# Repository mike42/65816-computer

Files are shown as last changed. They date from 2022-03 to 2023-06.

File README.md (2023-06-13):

# 65816 computer 

This is a prototype 65C816-based computer. It features a 1.8432 MHz processor, 1 megabyte of static RAM, a 65C22 I/O port, and an NXP SC16C752 dual UART.

The ROM contains a simple test program.

## Blog series

This is a learning project, and I am blogging about it as I progress.

- [A first look at the 65C816 processor](https://mike42.me/blog/2022-01-a-first-look-at-the-65c816-processor)
- [65C816 computer - initial prototype](https://mike42.me/blog/2022-02-65c816-computer-initial-prototype)
- [Interfacing an NXP UART to an 8-bit computer](https://mike42.me/blog/2022-02-interfacing-an-nxp-uart-to-an-8-bit-computer)
- [Let’s implement preemptive multitasking](https://mike42.me/blog/2022-03-lets-implement-preemptive-multitasking)
- [Building an emulator for my 65C816 computer](https://mike42.me/blog/2022-04-building-an-emulator-for-my-65c816-computer)
- [65C816 computer - second prototype](https://mike42.me/blog/2022-05-65c816-computer-second-prototype)
- [Building a 65C816 test board](https://mike42.me/blog/2022-06-building-a-65c816-test-board)
- [Let’s implement power-on self test (POST)](https://mike42.me/blog/2022-06-lets-implement-power-on-self-test-post)
- [Let’s make a bootloader – Part 1](https://mike42.me/blog/2022-09-lets-make-a-bootloader-part-1)
- [Let’s make a bootloader – Part 2](https://mike42.me/blog/2022-09-lets-make-a-bootloader-part-2)
- [Converting my 65C816 computer project to 3.3 V](https://mike42.me/blog/2023-01-converting-my-65c816-computer-project-to-3-3-v)

## Licenses & acknowledgement

With the exception of the files noted below, this work is © 2022-2023 Michael Billington, and is licensed under a [Creative Commons Attribution 4.0 International License](http://creativecommons.org/licenses/by/4.0/).

### 65816 emulator

The files in the `emulator/` directory are derived from Francesco Rigoni's work, primarily [lib65816](https://github.com/FrancescoRigoni/Lib65816). The emulator application is licensed under the GNU General Public License, version 3. Please see the README and LICENSE file in that directory for details.

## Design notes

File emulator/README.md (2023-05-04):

# 65816 emulator

This is an emulator for the custom 65C816 computer in this repository.

## Before you begin

You will need to assemble the computer's firmware to run the emulator. This is expected to be located at `../rom/rom.bin`.

To build the emulator itself, you will need:

- cmake - tested on 3.22.1
- GCC - tested on 11.2.0.
- Google test and boost libraries, installed on Debian via command below.

```
sudo apt install libgtest-dev libboost1.74-dev libboost-program-options1.74-dev libboost-filesystem1.74-dev
```

The emulator is only tested on Linux, and only implements hardware features which are used by the computer.

## Quick start

Compile and test a release build:

```
cmake -B build/release
make -j8 -C build/release all test
```

Run the emulator:

```
./build/release/emulator --rom ../rom/rom.bin
```

This will create a unix socket called 'serial1' in the current directory. In a separate terminal window, connect to this socket with minicom to interact with the emulated system.

```
minicom -D unix#serial
```

## Test mode

The emulator also functions as a unit test runner for the 65816 assembly projects in this repository. It uses debug information (a list of labels in VICE format) to locate and execute a `test_setup` routine, followed by every routine beginning with the name `test_`. If a routine leaves 0 in the accumulator after returning, it is recorded as a test pass. Any other value is recorded as a test failure.

An example project is located in the `test/resources/testing_example/` directory to show how this feature works. Execute the tests with the following command:

```
./build/release/emulator --test test/resources/testing_example/test.bin
```

## Fuzz tests

Fuzz tests are not built by default, since they depend on different build flags, as well as the use of clang.

Build them with the following commands:

```
CC=clang CXX=clang++ cmake -DFUZZ=1 -B build/fuzz
make -j8 -C build/fuzz
```

Next, run your fuzzer of choice from the `build/fuzz` directory.

## License & Attribution

This emulator is licensed under the GNU General Public License, version 3. See `LICENSE` for details.

It is derived from Francesco Rigoni's [lib65816](https://github.com/FrancescoRigoni/Lib65816), [Lib65816_Sample](https://github.com/FrancescoRigoni/Lib65816_Sample) and [Simple-Logger](https://github.com/FrancescoRigoni/Simple-Logger), with modifications by Michael Billington.

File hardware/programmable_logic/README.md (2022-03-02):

# Programmable logic for 65816 computer

This project PLD's to implement some functionality.

## PLD definitions

- `address_decode` - Provides chip select, read and write signals based on a memory address.

## Required tools

You will need quite a few tools to work with these files. Take a look at the `Makefile` in each directory to see how they are used.

### galette

Galette compiles the logic functions to a binary file which can be written to the PLD. See [simon-frankau/galette](https://github.com/simon-frankau/galette).

### pin_to_csv

This converts the output of galette to an input for KiPart. It was written for this project, and is included in the repo.

### KiPart

KiPart generates KiCAD symbols for the programmed PLD's. See [devbisme/KiPart](https://github.com/devbisme/KiPart)

```
pip3 install kipart
```

### minipro

This is a command-line utility which I use to program these chips. See [DavidGriffith/minipro/](https://gitlab.com/DavidGriffith/minipro/)

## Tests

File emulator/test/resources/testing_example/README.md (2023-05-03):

# Example test project

This is an assembled test project: the emulator is able to run tests in the linker binary output (test.bin), discovered by parsing the label file (test.lbl).

Source and build script are provided for reference.

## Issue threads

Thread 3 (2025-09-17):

Alternative reset button symbol.

Anathae, 2025-09-17:
As noted in your Jan 2023 blog posting, the pinout of the tactile switch used for the reset switch did not match the mapping between the schematic pins and the PCB pins.  The pinout you used, SW_TH_Tactile_Omron_BF-10xx, described in the datasheet at https://omronfs.omron.com/en_US/ecb/products/pdf/en-b3f.pdf, is better matched to the schematic symbol for SW_MEC_5E.  Pins 1 and 2 are one side of the button, and 3 and 4 are the other side of the button.  With this symbol and pinout, pin 1 on the pcb would be mapped to pins 3 and 4 on the schematic symbol, and pin 2 on the pcb would be mapped to pins 1 and 2 on the schematic symbol.

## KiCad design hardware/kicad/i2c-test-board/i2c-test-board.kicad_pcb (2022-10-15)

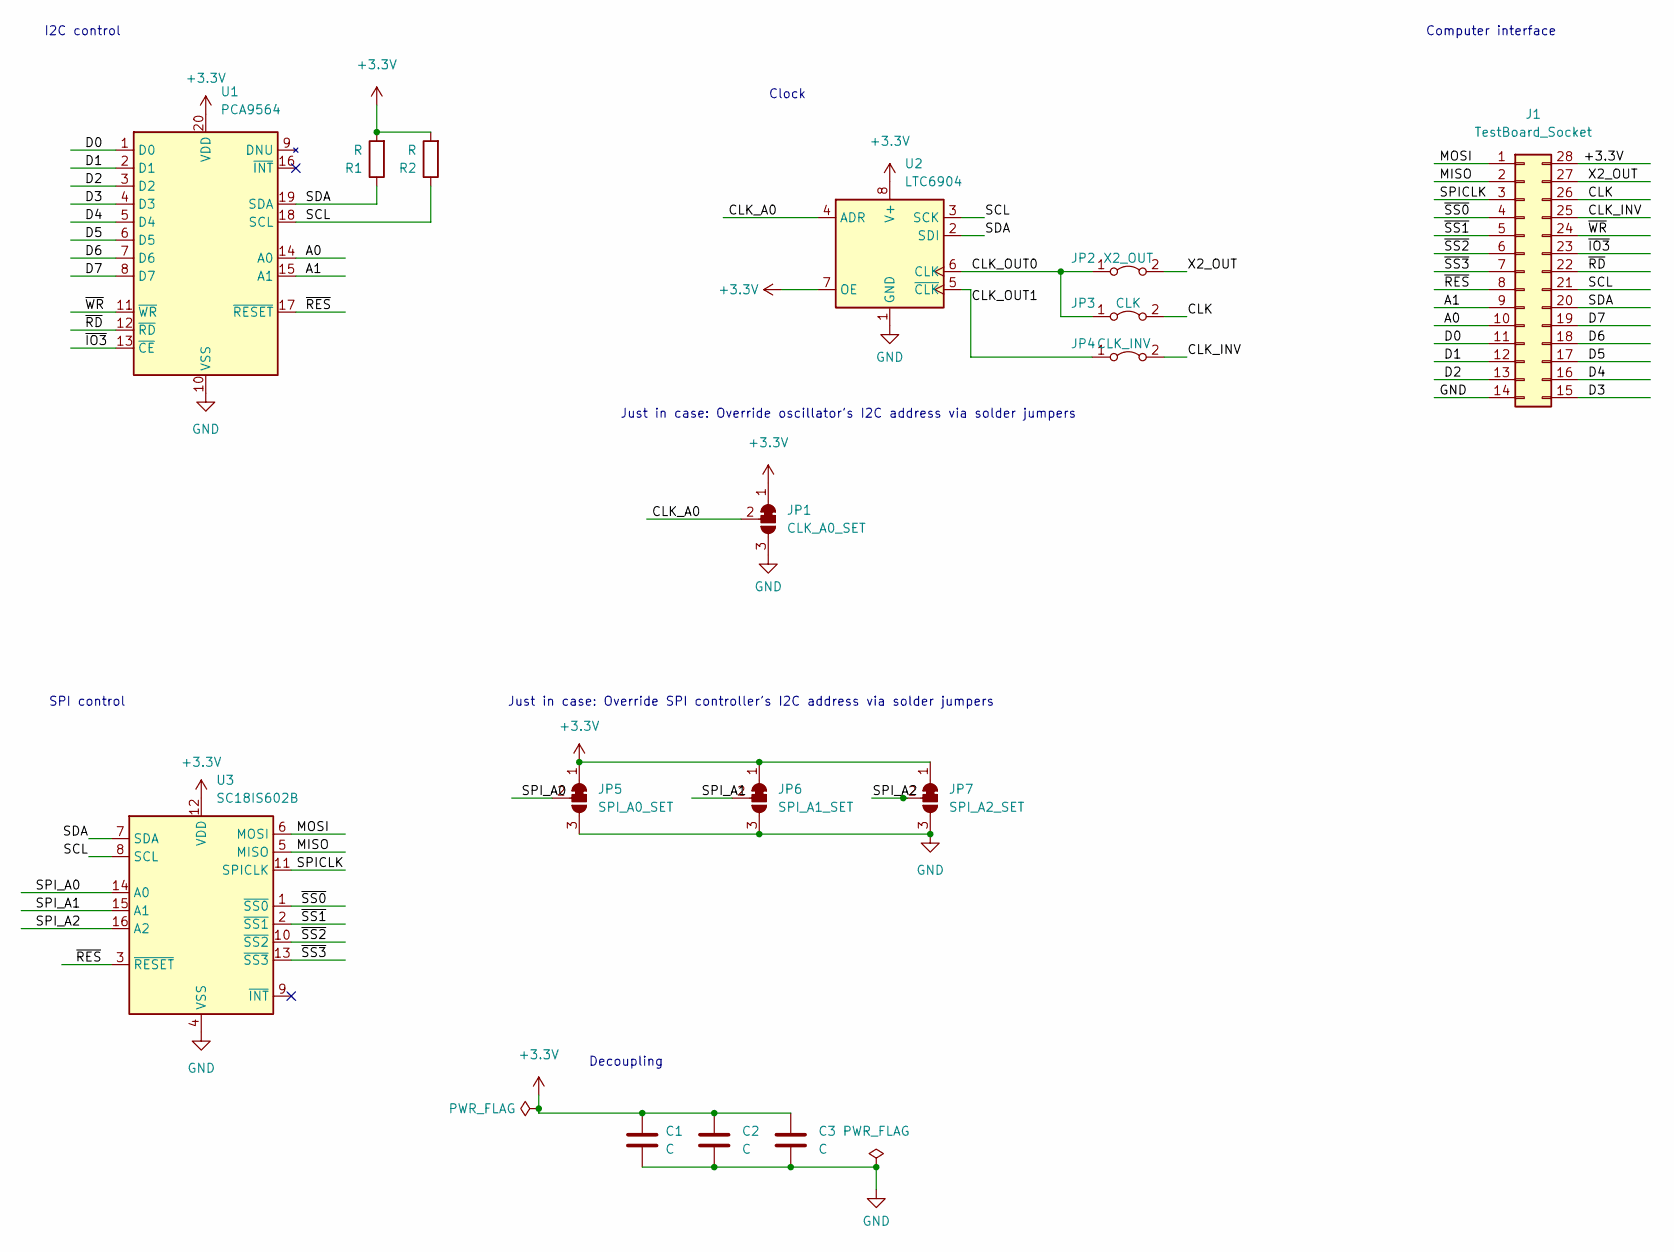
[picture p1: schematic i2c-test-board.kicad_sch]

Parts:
C1, C2, C3: C; C_0603_1608Metric_Pad1.08x0.95mm_HandSolder
J1: TestBoard_Socket; DIP-28_W15.24mm_Socket
JP1: CLK_A0_SET; SolderJumper-3_P1.3mm_Bridged12_RoundedPad1.0x1.5mm
JP2: X2_OUT; SolderJumper-2_P1.3mm_Bridged_RoundedPad1.0x1.5mm
JP3: CLK; SolderJumper-2_P1.3mm_Bridged_RoundedPad1.0x1.5mm
JP4: CLK_INV; SolderJumper-2_P1.3mm_Bridged_RoundedPad1.0x1.5mm
JP5: SPI_A0_SET; SolderJumper-3_P1.3mm_Bridged12_RoundedPad1.0x1.5mm
JP6: SPI_A1_SET; SolderJumper-3_P1.3mm_Bridged12_RoundedPad1.0x1.5mm
JP7: SPI_A2_SET; SolderJumper-3_P1.3mm_Bridged12_RoundedPad1.0x1.5mm
R1, R2: R; R_0603_1608Metric_Pad0.98x0.95mm_HandSolder
U1: PCA9564; TSSOP-20_4.4x6.5mm_P0.65mm
U2: LTC6904; MSOP-8_3x3mm_P0.65mm
U3: SC18IS602B; TSSOP-16_4.4x5mm_P0.65mm

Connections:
+3.3V: C1.1, C2.1, C3.1, J1.28, JP1.1 (A), JP5.1 (A), JP6.1 (A), JP7.1 (A), R1.2, R2.2, U1.20 (VDD), U2.7 (OE), U2.8 (V+), U3.12 (VDD)
/A0: J1.10, U1.14 (A0)
/A1: J1.9, U1.15 (A1)
/CLK: J1.26, JP3.2 (B)
/CLK_A0: JP1.2 (C), U2.4 (ADR)
/CLK_INV: J1.25, JP4.2 (B)
/CLK_OUT0: JP2.1 (A), JP3.1 (A), U2.6 (CLK)
/CLK_OUT1: JP4.1 (A), U2.5 (~CLK)
/D0: J1.11, U1.1 (D0)
/D1: J1.12, U1.2 (D1)
/D2: J1.13, U1.3 (D2)
/D3: J1.15, U1.4 (D3)
/D4: J1.16, U1.5 (D4)
/D5: J1.17, U1.6 (D5)
/D6: J1.18, U1.7 (D6)
/D7: J1.19, U1.8 (D7)
/MISO: J1.2, U3.5 (MISO)
/MOSI: J1.1, U3.6 (MOSI)
/SCL: J1.21, R2.1, U1.18 (SCL), U2.3 (SCK), U3.8 (SCL)
/SDA: J1.20, R1.1, U1.19 (SDA), U2.2 (SDI), U3.7 (SDA)
/SPICLK: J1.3, U3.11 (SPICLK)
/SPI_A0: JP5.2 (C), U3.14 (A0)
/SPI_A1: JP6.2 (C), U3.15 (A1)
/SPI_A2: JP7.2 (C), U3.16 (A2)
/X2_OUT: J1.27, JP2.2 (B)
/~IO3: J1.23, U1.13 (~CE)
/~RD: J1.22, U1.12 (~RD)
/~RES: J1.8, U1.17 (~RESET), U3.3 (~RESET)
/~SS0: J1.4, U3.1 (~SS0)
/~SS1: J1.5, U3.2 (~SS1)
/~SS2: J1.6, U3.10 (~SS2)
/~SS3: J1.7, U3.13 (~SS3)
/~WR: J1.24, U1.11 (~WR)
GND: C1.2, C2.2, C3.2, J1.14, JP1.3 (B), JP5.3 (B), JP6.3 (B), JP7.3 (B), U1.10 (VSS), U2.1 (GND), U3.4 (VSS)

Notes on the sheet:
I2C control
Just in case: Override oscillator's I2C address via solder jumpers
Computer interface
Clock
Decoupling
SPI control
Just in case: Override SPI controller's I2C address via solder jumpers

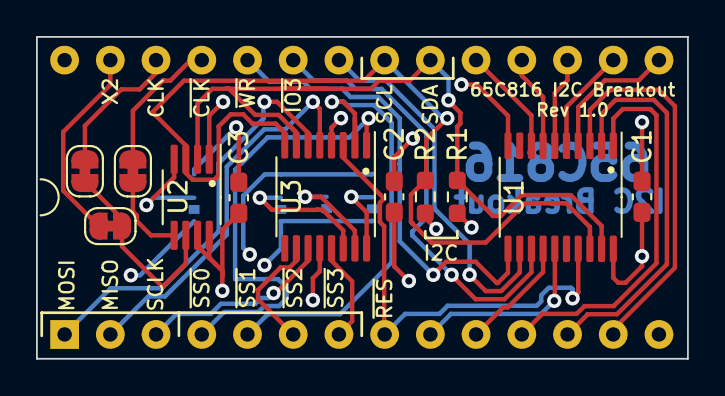
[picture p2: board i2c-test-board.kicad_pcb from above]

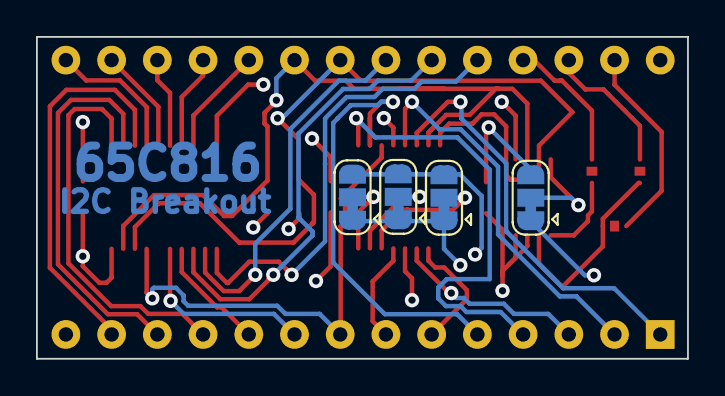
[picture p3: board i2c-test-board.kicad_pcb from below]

Board: 4 copper layers, 36.2 x 17.9 mm, 16 parts (4 on the bottom side), 34 nets.

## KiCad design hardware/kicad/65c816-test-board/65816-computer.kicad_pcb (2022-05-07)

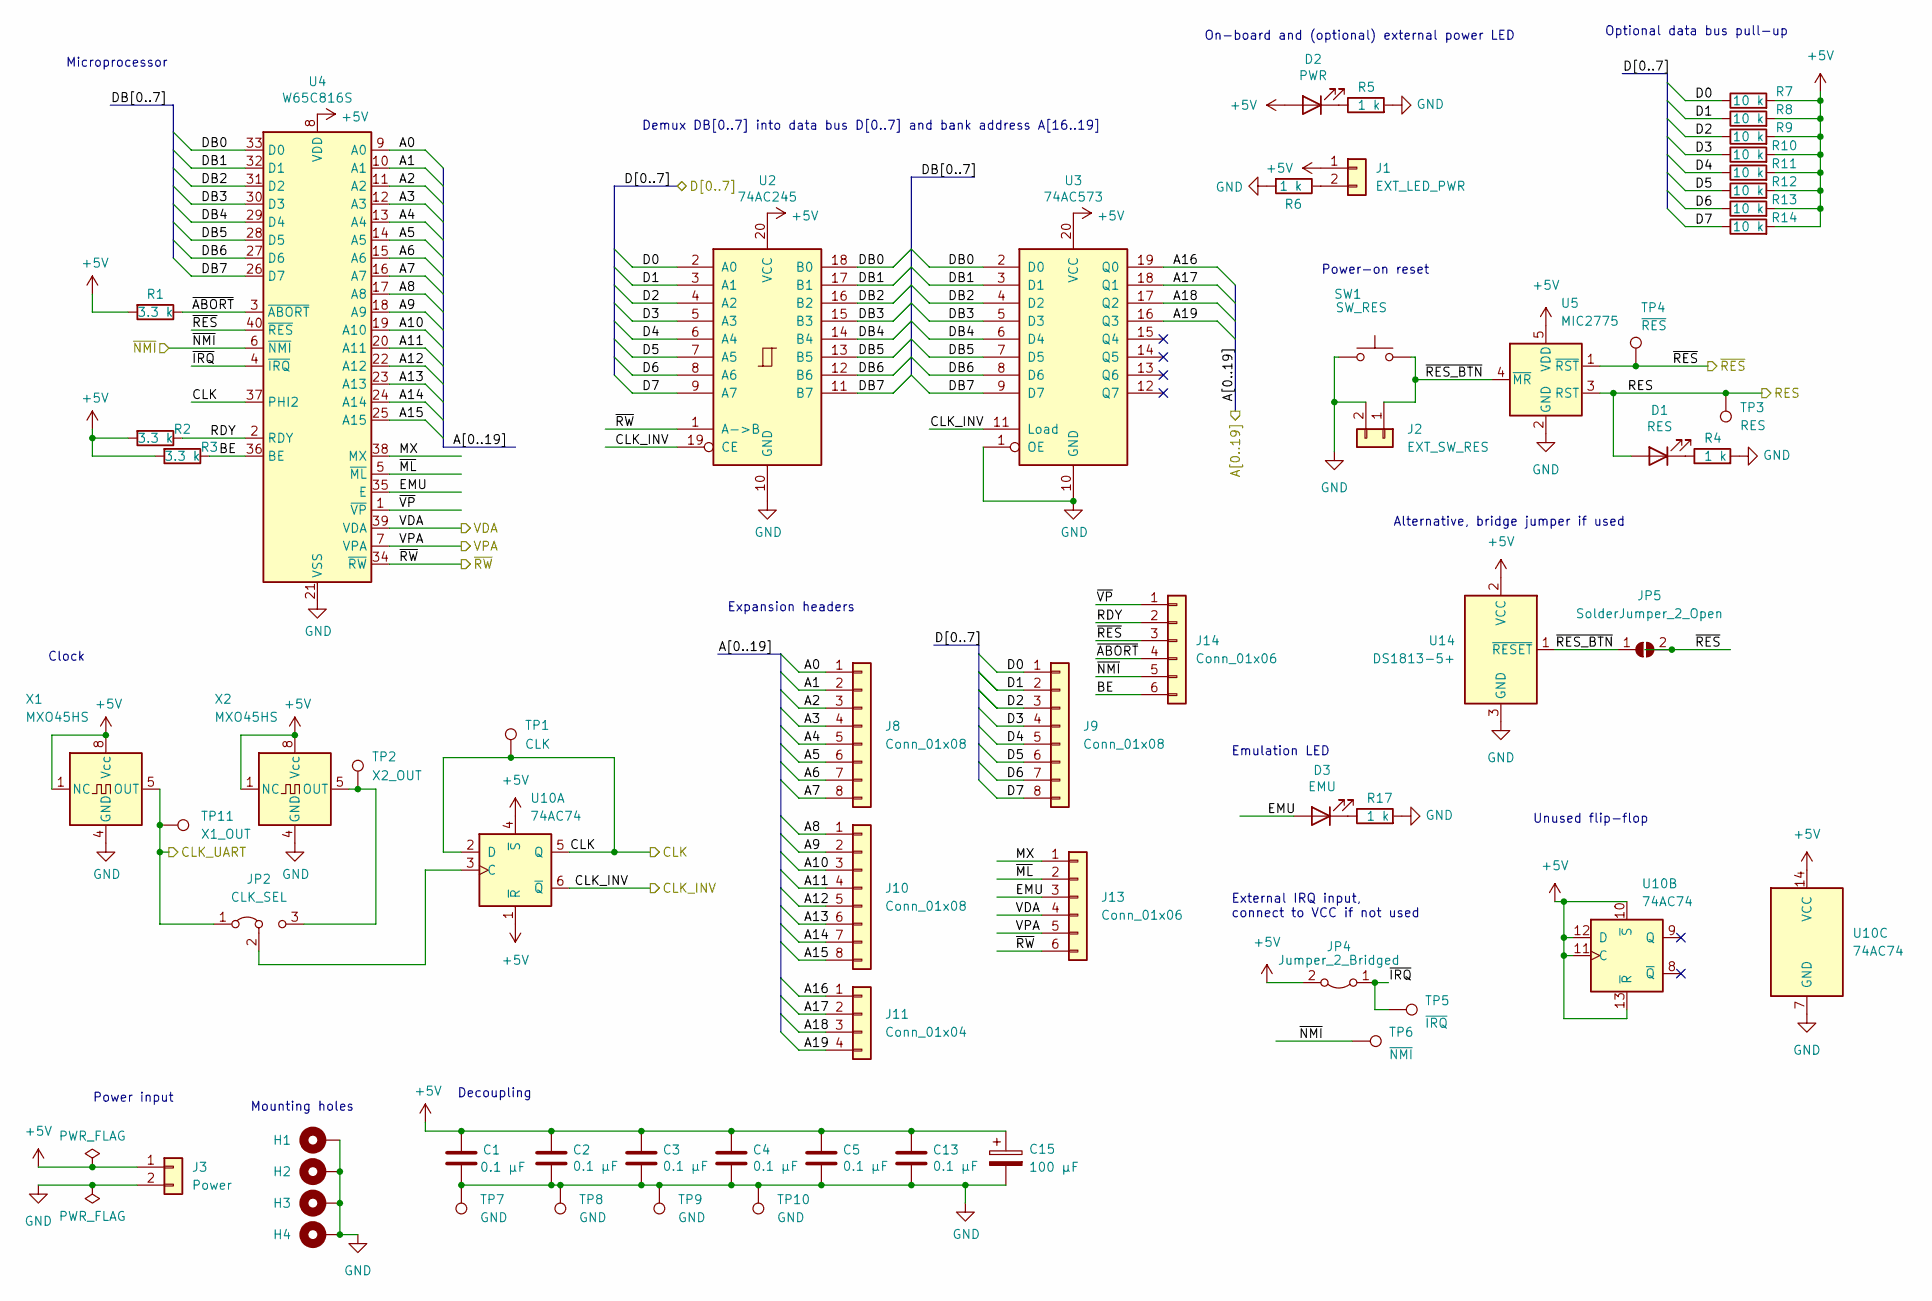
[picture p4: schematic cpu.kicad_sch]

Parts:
C1, C2, C3, C4, C5, C13: 0.1 µF; C_0603_1608Metric_Pad1.08x0.95mm_HandSolder
C15: 100 µF; CP_Radial_D6.3mm_P2.50mm
D1: RES; LED_0603_1608Metric_Pad1.05x0.95mm_HandSolder
D2: PWR; LED_0603_1608Metric_Pad1.05x0.95mm_HandSolder
D3: EMU; LED_0603_1608Metric_Pad1.05x0.95mm_HandSolder
H1, H2, H3, H4: MountingHole_Pad; MountingHole_3.2mm_M3_Pad_Via
J1: EXT_LED_PWR; PinHeader_1x02_P2.54mm_Vertical
J2: EXT_SW_RES; PinHeader_1x02_P2.54mm_Vertical
J3: Power; JST_XH_B2B-XH-A_1x02_P2.50mm_Vertical
J8, J9, J10: Conn_01x08; PinHeader_1x08_P2.54mm_Vertical
J11: Conn_01x04; PinHeader_1x04_P2.54mm_Vertical
J13, J14: Conn_01x06; PinHeader_1x06_P2.54mm_Vertical
JP2: CLK_SEL; PinHeader_1x03_P2.54mm_Vertical
JP4: Jumper_2_Bridged; PinHeader_1x02_P2.54mm_Vertical
JP5: SolderJumper_2_Open; SolderJumper-2_P1.3mm_Open_RoundedPad1.0x1.5mm
R1, R2, R3: 3.3 k; R_0603_1608Metric_Pad0.98x0.95mm_HandSolder
R4, R5, R6, R17: 1 k; R_0603_1608Metric_Pad0.98x0.95mm_HandSolder
R7, R8, R9, R10, R11, R12, R13, R14: 10 k; R_0603_1608Metric_Pad0.98x0.95mm_HandSolder
SW1: SW_RES; SW_TH_Tactile_Omron_B3F-10xx
TP1: CLK; TestPoint_Keystone_5005-5009_Compact
TP2: X2_OUT; TestPoint_Keystone_5005-5009_Compact
TP3: RES; TestPoint_Pad_D1.5mm
TP4: ~{RES}; TestPoint_Keystone_5005-5009_Compact
TP5: ~{IRQ}; TestPoint_Keystone_5005-5009_Compact
TP6: ~{NMI}; TestPoint_Keystone_5005-5009_Compact
TP7, TP8, TP9, TP10: GND; TestPoint_Keystone_5005-5009_Compact
TP11: X1_OUT; TestPoint_Keystone_5005-5009_Compact
U2: 74AC245; DIP-20_W7.62mm_Socket
U3: 74AC573; DIP-20_W7.62mm_Socket
U4: W65C816S; DIP-40_W15.24mm_Socket
U5: MIC2775; SOT-23-5_HandSoldering
U10: 74AC74; DIP-14_W7.62mm_Socket
U14: DS1813-5+; TO-92_Inline
X1, X2: MXO45HS; Oscillator_DIP-8

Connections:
+5V: C1.1, C2.1, C3.1, C4.1, C5.1, C13.1, C15.1, D2.2 (A), J1.1, J3.1, JP4.2 (B), R1.2, R2.2, R3.2, R7.2, R8.2, R9.2, R10.2, R11.2, R12.2, R13.2, R14.2, U2.20 (VCC), U3.20 (VCC), U4.8 (VDD), U5.5 (VDD), U10.1 (~R), U10.4 (~S), U10.10 (~S), U10.11 (C), U10.12 (D), U10.13 (~R), U10.14 (VCC), U14.2 (VCC), X1.1 (NC), X1.8 (Vcc), X2.1 (NC), X2.8 (Vcc); also elsewhere on the board
/CPU& Bank Address Latching/A0: J8.1, U4.9 (A0); also elsewhere on the board
/CPU& Bank Address Latching/A1: J8.2, U4.10 (A1); also elsewhere on the board
/CPU& Bank Address Latching/A2: J8.3, U4.11 (A2); also elsewhere on the board
/CPU& Bank Address Latching/A3: J8.4, U4.12 (A3); also elsewhere on the board
/CPU& Bank Address Latching/A4: J8.5, U4.13 (A4); also elsewhere on the board
/CPU& Bank Address Latching/A5: J8.6, U4.14 (A5); also elsewhere on the board
/CPU& Bank Address Latching/A6: J8.7, U4.15 (A6); also elsewhere on the board
/CPU& Bank Address Latching/A7: J8.8, U4.16 (A7); also elsewhere on the board
/CPU& Bank Address Latching/A8: J10.1, U4.17 (A8); also elsewhere on the board
/CPU& Bank Address Latching/A9: J10.2, U4.18 (A9); also elsewhere on the board
/CPU& Bank Address Latching/A10: J10.3, U4.19 (A10); also elsewhere on the board
/CPU& Bank Address Latching/A11: J10.4, U4.20 (A11); also elsewhere on the board
/CPU& Bank Address Latching/A12: J10.5, U4.22 (A12); also elsewhere on the board
/CPU& Bank Address Latching/A13: J10.6, U4.23 (A13); also elsewhere on the board
/CPU& Bank Address Latching/A14: J10.7, U4.24 (A14); also elsewhere on the board
/CPU& Bank Address Latching/A15: J10.8, U4.25 (A15); also elsewhere on the board
/CPU& Bank Address Latching/A16: J11.1, U3.19 (Q0); also elsewhere on the board
/CPU& Bank Address Latching/A17: J11.2, U3.18 (Q1); also elsewhere on the board
/CPU& Bank Address Latching/A18: J11.3, U3.17 (Q2); also elsewhere on the board
/CPU& Bank Address Latching/A19: J11.4, U3.16 (Q3); also elsewhere on the board
/CPU& Bank Address Latching/BE: J14.6, R3.1, U4.36 (BE)
/CPU& Bank Address Latching/CLK: TP1.1, U4.37 (PHI2), U10.2 (D), U10.5 (Q); also elsewhere on the board
/CPU& Bank Address Latching/CLK_INV: U2.19 (CE), U3.11 (Load), U10.6 (~Q)
/CPU& Bank Address Latching/CLK_UART: JP2.1 (A), TP11.1, X1.5 (OUT); also elsewhere on the board
/CPU& Bank Address Latching/D0: J9.1, R7.1, U2.2 (A0); also elsewhere on the board
/CPU& Bank Address Latching/D1: J9.2, R8.1, U2.3 (A1); also elsewhere on the board
/CPU& Bank Address Latching/D2: J9.3, R9.1, U2.4 (A2); also elsewhere on the board
/CPU& Bank Address Latching/D3: J9.4, R10.1, U2.5 (A3); also elsewhere on the board
/CPU& Bank Address Latching/D4: J9.5, R11.1, U2.6 (A4); also elsewhere on the board
/CPU& Bank Address Latching/D5: J9.6, R12.1, U2.7 (A5); also elsewhere on the board
/CPU& Bank Address Latching/D6: J9.7, R13.1, U2.8 (A6); also elsewhere on the board
/CPU& Bank Address Latching/D7: J9.8, R14.1, U2.9 (A7); also elsewhere on the board
/CPU& Bank Address Latching/DB0: U2.18 (B0), U3.2 (D0), U4.33 (D0)
/CPU& Bank Address Latching/DB1: U2.17 (B1), U3.3 (D1), U4.32 (D1)
/CPU& Bank Address Latching/DB2: U2.16 (B2), U3.4 (D2), U4.31 (D2)
/CPU& Bank Address Latching/DB3: U2.15 (B3), U3.5 (D3), U4.30 (D3)
/CPU& Bank Address Latching/DB4: U2.14 (B4), U3.6 (D4), U4.29 (D4)
/CPU& Bank Address Latching/DB5: U2.13 (B5), U3.7 (D5), U4.28 (D5)
/CPU& Bank Address Latching/DB6: U2.12 (B6), U3.8 (D6), U4.27 (D6)
/CPU& Bank Address Latching/DB7: U2.11 (B7), U3.9 (D7), U4.26 (D7)
/CPU& Bank Address Latching/EMU: D3.2 (A), J13.3, U4.35 (E)
/CPU& Bank Address Latching/MX: J13.1, U4.38 (MX)
/CPU& Bank Address Latching/RDY: J14.2, R2.1, U4.2 (RDY)
/CPU& Bank Address Latching/RES: D1.2 (A), TP3.1, U5.3 (RST); also elsewhere on the board
/CPU& Bank Address Latching/VDA: J13.4, U4.39 (VDA); also elsewhere on the board
/CPU& Bank Address Latching/VPA: J13.5, U4.7 (VPA); also elsewhere on the board
/CPU& Bank Address Latching/~ABORT: J14.4, R1.1, U4.3 (~ABORT)
/CPU& Bank Address Latching/~IRQ: JP4.1 (A), TP5.1, U4.4 (~IRQ)
/CPU& Bank Address Latching/~ML: J13.2, U4.5 (~ML)
/CPU& Bank Address Latching/~NMI: J14.5, TP6.1, U4.6 (~NMI); also elsewhere on the board
/CPU& Bank Address Latching/~RES_BTN: J2.1, JP5.1 (A), SW1.2, U5.4 (~MR), U14.1 (~RESET)
/CPU& Bank Address Latching/~RES: J14.3, JP5.2 (B), TP4.1, U4.40 (~RES), U5.1 (~RST); also elsewhere on the board
/CPU& Bank Address Latching/~RW: J13.6, U2.1 (A->B), U4.34 (~RW); also elsewhere on the board
/CPU& Bank Address Latching/~VP: J14.1, U4.1 (~VP)
GND: C1.2, C2.2, C3.2, C4.2, C5.2, C13.2, C15.2, H1.1, H2.1, H3.1, H4.1, J2.2, J3.2, R4.2, R5.2, R6.2, R17.2, SW1.1, TP7.1, TP8.1, TP9.1, TP10.1, U2.10 (GND), U3.1 (OE), U3.10 (GND), U4.21 (VSS), U5.2 (GND), U10.7 (GND), U14.3 (GND), X1.4 (GND), X2.4 (GND); also elsewhere on the board
unnamed: D1.1 (K), R4.1
unnamed: D2.1 (K), R5.1
unnamed: D3.1 (K), R17.1
unnamed: J1.2, R6.1
unnamed: JP2.2 (C), U10.3 (C)
unnamed 127: JP2.3 (B), TP2.1, X2.5 (OUT); also elsewhere on the board

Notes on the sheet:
Power input
Unused flip-flop
Expansion headers
On-board and (optional) external power LED
Microprocessor
Clock
Alternative, bridge jumper if used
Emulation LED
Demux DB[0..7] into data bus D[0..7] and bank address A[16..19]
Decoupling
Mounting holes
External IRQ input, connect to VCC if not used
Power-on reset
Optional data bus pull-up

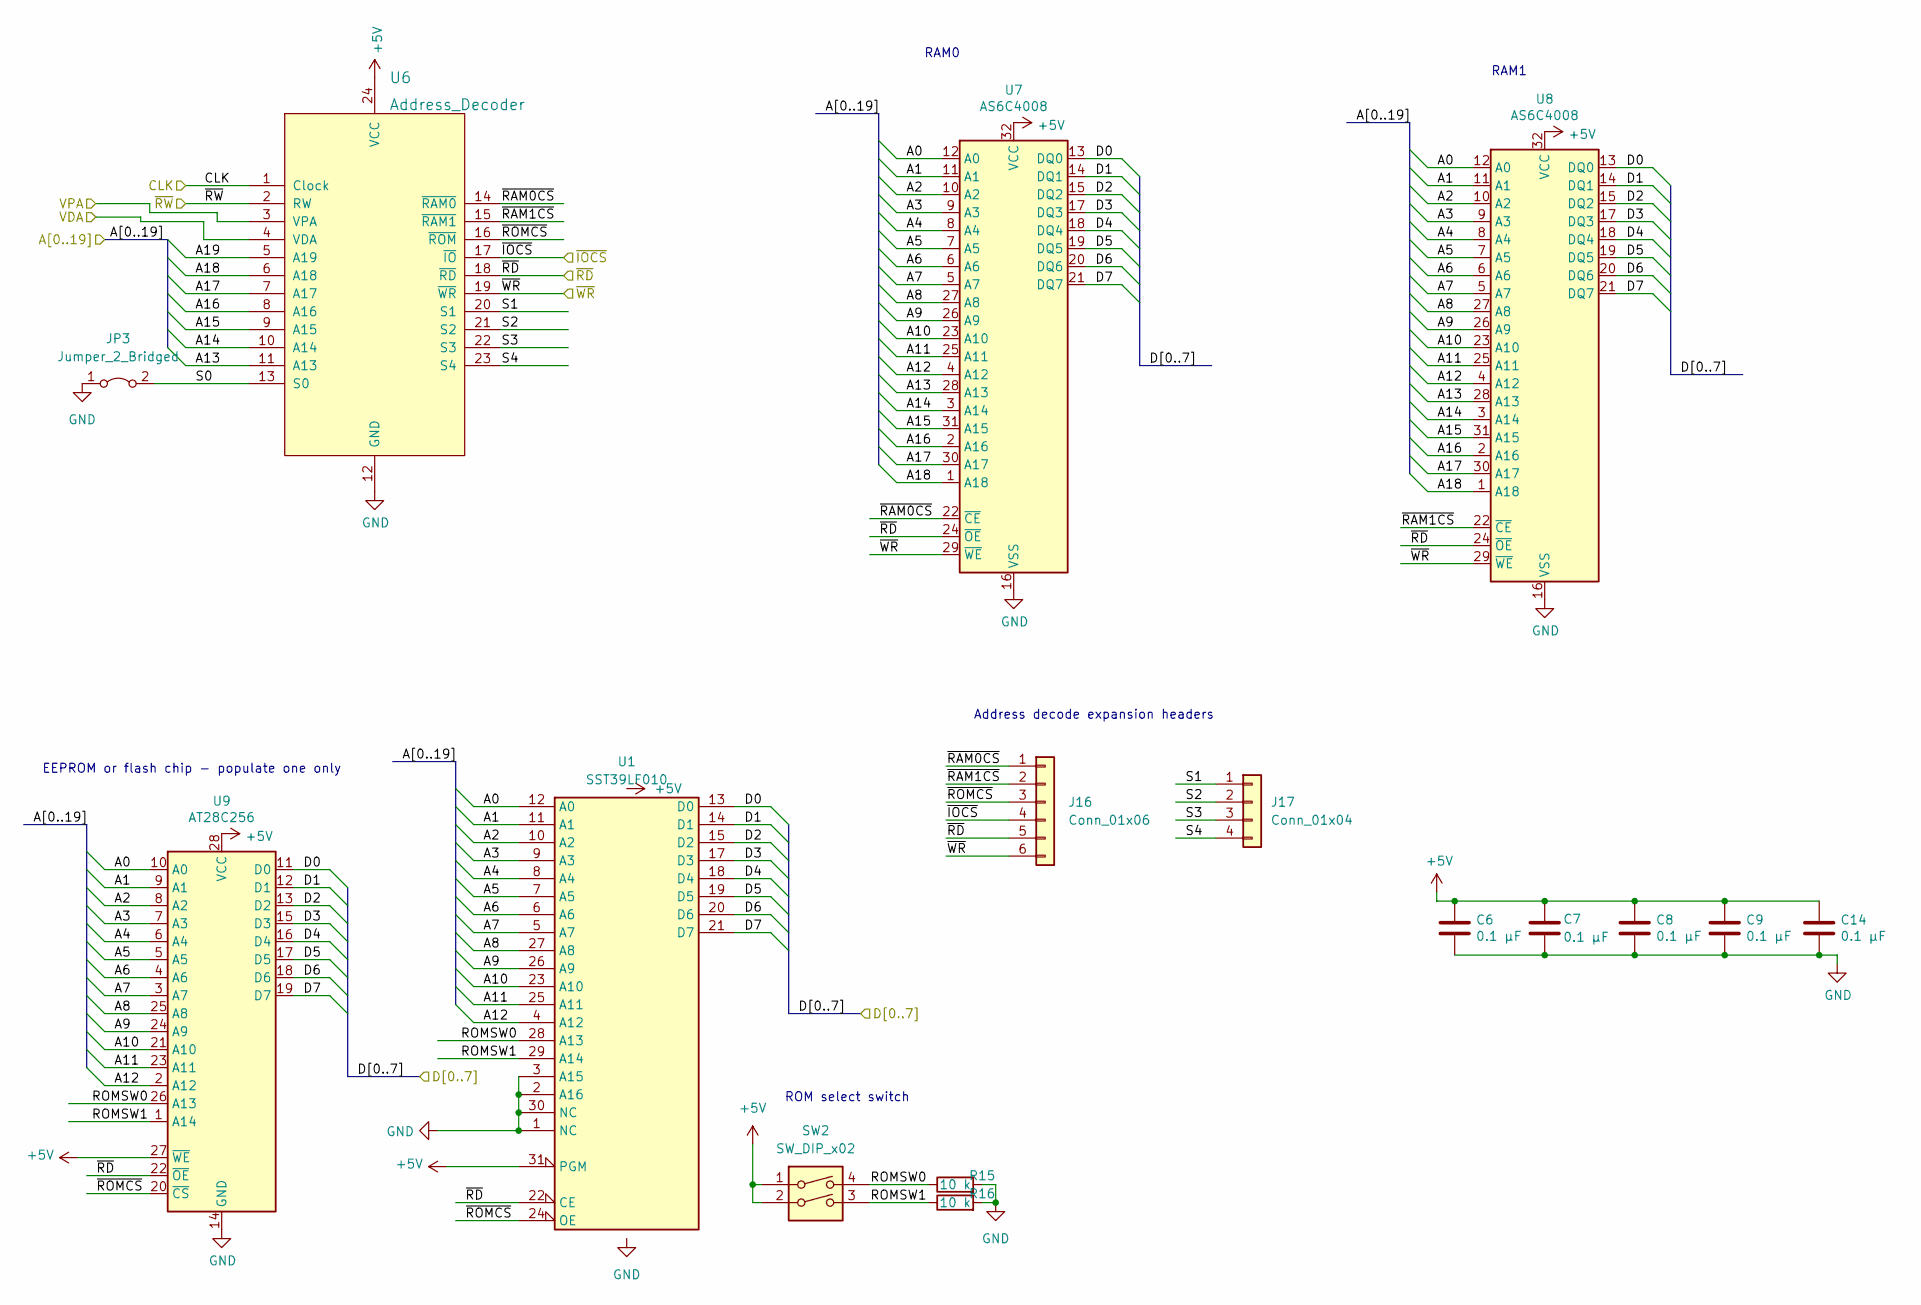
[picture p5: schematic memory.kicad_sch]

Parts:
C6, C7, C8, C9, C14: 0.1 µF; C_0603_1608Metric_Pad1.08x0.95mm_HandSolder
J16: Conn_01x06; PinHeader_1x06_P2.54mm_Vertical
J17: Conn_01x04; PinHeader_1x04_P2.54mm_Vertical
JP3: Jumper_2_Bridged; PinHeader_1x02_P2.54mm_Vertical
R15, R16: 10 k; R_0603_1608Metric_Pad0.98x0.95mm_HandSolder
SW2: SW_DIP_x02; SW_DIP_SPSTx02_Slide_6.7x6.64mm_W8.61mm_P2.54mm_LowProfile
U1: SST39LF010; PLCC-32_11.4x14.0mm_P1.27mm
U6: Address_Decoder; DIP-24_W7.62mm_Socket
U7, U8: AS6C4008; DIP-32_W15.24mm_Socket
U9: AT28C256; DIP-28_W15.24mm_Socket

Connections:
+5V: C6.1, C7.1, C8.1, C9.1, C14.1, SW2.1, SW2.2, U1.31 (PGM), U1.32 (VCC), U6.24 (VCC), U7.32 (VCC), U8.32 (VCC), U9.27 (~WE), U9.28 (VCC); also elsewhere on the board
/CPU& Bank Address Latching/A0: U1.12 (A0), U7.12 (A0), U8.12 (A0), U9.10 (A0); also elsewhere on the board
/CPU& Bank Address Latching/A1: U1.11 (A1), U7.11 (A1), U8.11 (A1), U9.9 (A1); also elsewhere on the board
/CPU& Bank Address Latching/A2: U1.10 (A2), U7.10 (A2), U8.10 (A2), U9.8 (A2); also elsewhere on the board
/CPU& Bank Address Latching/A3: U1.9 (A3), U7.9 (A3), U8.9 (A3), U9.7 (A3); also elsewhere on the board
/CPU& Bank Address Latching/A4: U1.8 (A4), U7.8 (A4), U8.8 (A4), U9.6 (A4); also elsewhere on the board
/CPU& Bank Address Latching/A5: U1.7 (A5), U7.7 (A5), U8.7 (A5), U9.5 (A5); also elsewhere on the board
/CPU& Bank Address Latching/A6: U1.6 (A6), U7.6 (A6), U8.6 (A6), U9.4 (A6); also elsewhere on the board
/CPU& Bank Address Latching/A7: U1.5 (A7), U7.5 (A7), U8.5 (A7), U9.3 (A7); also elsewhere on the board
/CPU& Bank Address Latching/A8: U1.27 (A8), U7.27 (A8), U8.27 (A8), U9.25 (A8); also elsewhere on the board
/CPU& Bank Address Latching/A9: U1.26 (A9), U7.26 (A9), U8.26 (A9), U9.24 (A9); also elsewhere on the board
/CPU& Bank Address Latching/A10: U1.23 (A10), U7.23 (A10), U8.23 (A10), U9.21 (A10); also elsewhere on the board
/CPU& Bank Address Latching/A11: U1.25 (A11), U7.25 (A11), U8.25 (A11), U9.23 (A11); also elsewhere on the board
/CPU& Bank Address Latching/A12: U1.4 (A12), U7.4 (A12), U8.4 (A12), U9.2 (A12); also elsewhere on the board
/CPU& Bank Address Latching/A13: U6.11 (A13), U7.28 (A13), U8.28 (A13); also elsewhere on the board
/CPU& Bank Address Latching/A14: U6.10 (A14), U7.3 (A14), U8.3 (A14); also elsewhere on the board
/CPU& Bank Address Latching/A15: U6.9 (A15), U7.31 (A15), U8.31 (A15); also elsewhere on the board
/CPU& Bank Address Latching/A16: U6.8 (A16), U7.2 (A16), U8.2 (A16); also elsewhere on the board
/CPU& Bank Address Latching/A17: U6.7 (A17), U7.30 (A17), U8.30 (A17); also elsewhere on the board
/CPU& Bank Address Latching/A18: U6.6 (A18), U7.1 (A18), U8.1 (A18); also elsewhere on the board
/CPU& Bank Address Latching/A19: U6.5 (A19); also elsewhere on the board
/CPU& Bank Address Latching/CLK: U6.1 (Clock); also elsewhere on the board
/CPU& Bank Address Latching/D0: U1.13 (D0), U7.13 (DQ0), U8.13 (DQ0), U9.11 (D0); also elsewhere on the board
/CPU& Bank Address Latching/D1: U1.14 (D1), U7.14 (DQ1), U8.14 (DQ1), U9.12 (D1); also elsewhere on the board
/CPU& Bank Address Latching/D2: U1.15 (D2), U7.15 (DQ2), U8.15 (DQ2), U9.13 (D2); also elsewhere on the board
/CPU& Bank Address Latching/D3: U1.17 (D3), U7.17 (DQ3), U8.17 (DQ3), U9.15 (D3); also elsewhere on the board
/CPU& Bank Address Latching/D4: U1.18 (D4), U7.18 (DQ4), U8.18 (DQ4), U9.16 (D4); also elsewhere on the board
/CPU& Bank Address Latching/D5: U1.19 (D5), U7.19 (DQ5), U8.19 (DQ5), U9.17 (D5); also elsewhere on the board
/CPU& Bank Address Latching/D6: U1.20 (D6), U7.20 (DQ6), U8.20 (DQ6), U9.18 (D6); also elsewhere on the board
/CPU& Bank Address Latching/D7: U1.21 (D7), U7.21 (DQ7), U8.21 (DQ7), U9.19 (D7); also elsewhere on the board
/CPU& Bank Address Latching/VDA: U6.4 (VDA); also elsewhere on the board
/CPU& Bank Address Latching/VPA: U6.3 (VPA); also elsewhere on the board
/CPU& Bank Address Latching/~RW: U6.2 (RW); also elsewhere on the board
/IO/~IOCS: J16.4, U6.17 (~IO); also elsewhere on the board
/Memory/ROMSW0: R15.1, SW2.4, U1.28 (A13), U9.26 (A13)
/Memory/ROMSW1: R16.1, SW2.3, U1.29 (A14), U9.1 (A14)
/Memory/S0: JP3.2 (B), U6.13 (S0)
/Memory/S1: J17.1, U6.20 (S1)
/Memory/S2: J17.2, U6.21 (S2)
/Memory/S3: J17.3, U6.22 (S3)
/Memory/S4: J17.4, U6.23 (S4)
/Memory/~RAM0CS: J16.1, U6.14 (~RAM0), U7.22 (~CE)
/Memory/~RAM1CS: J16.2, U6.15 (~RAM1), U8.22 (~CE)
/Memory/~RD: J16.5, U1.22 (CE), U6.18 (~RD), U7.24 (~OE), U8.24 (~OE), U9.22 (~OE); also elsewhere on the board
/Memory/~ROMCS: J16.3, U1.24 (OE), U6.16 (~ROM), U9.20 (~CS)
/Memory/~WR: J16.6, U6.19 (~WR), U7.29 (~WE), U8.29 (~WE); also elsewhere on the board
GND: C6.2, C7.2, C8.2, C9.2, C14.2, JP3.1 (A), R15.2, R16.2, U1.1 (NC), U1.2 (A16), U1.3 (A15), U1.16 (GND), U1.30 (NC), U6.12 (GND), U7.16 (VSS), U8.16 (VSS), U9.14 (GND); also elsewhere on the board

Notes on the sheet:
EEPROM or flash chip - populate one only
ROM select switch
Address decode expansion headers
RAM0
RAM1

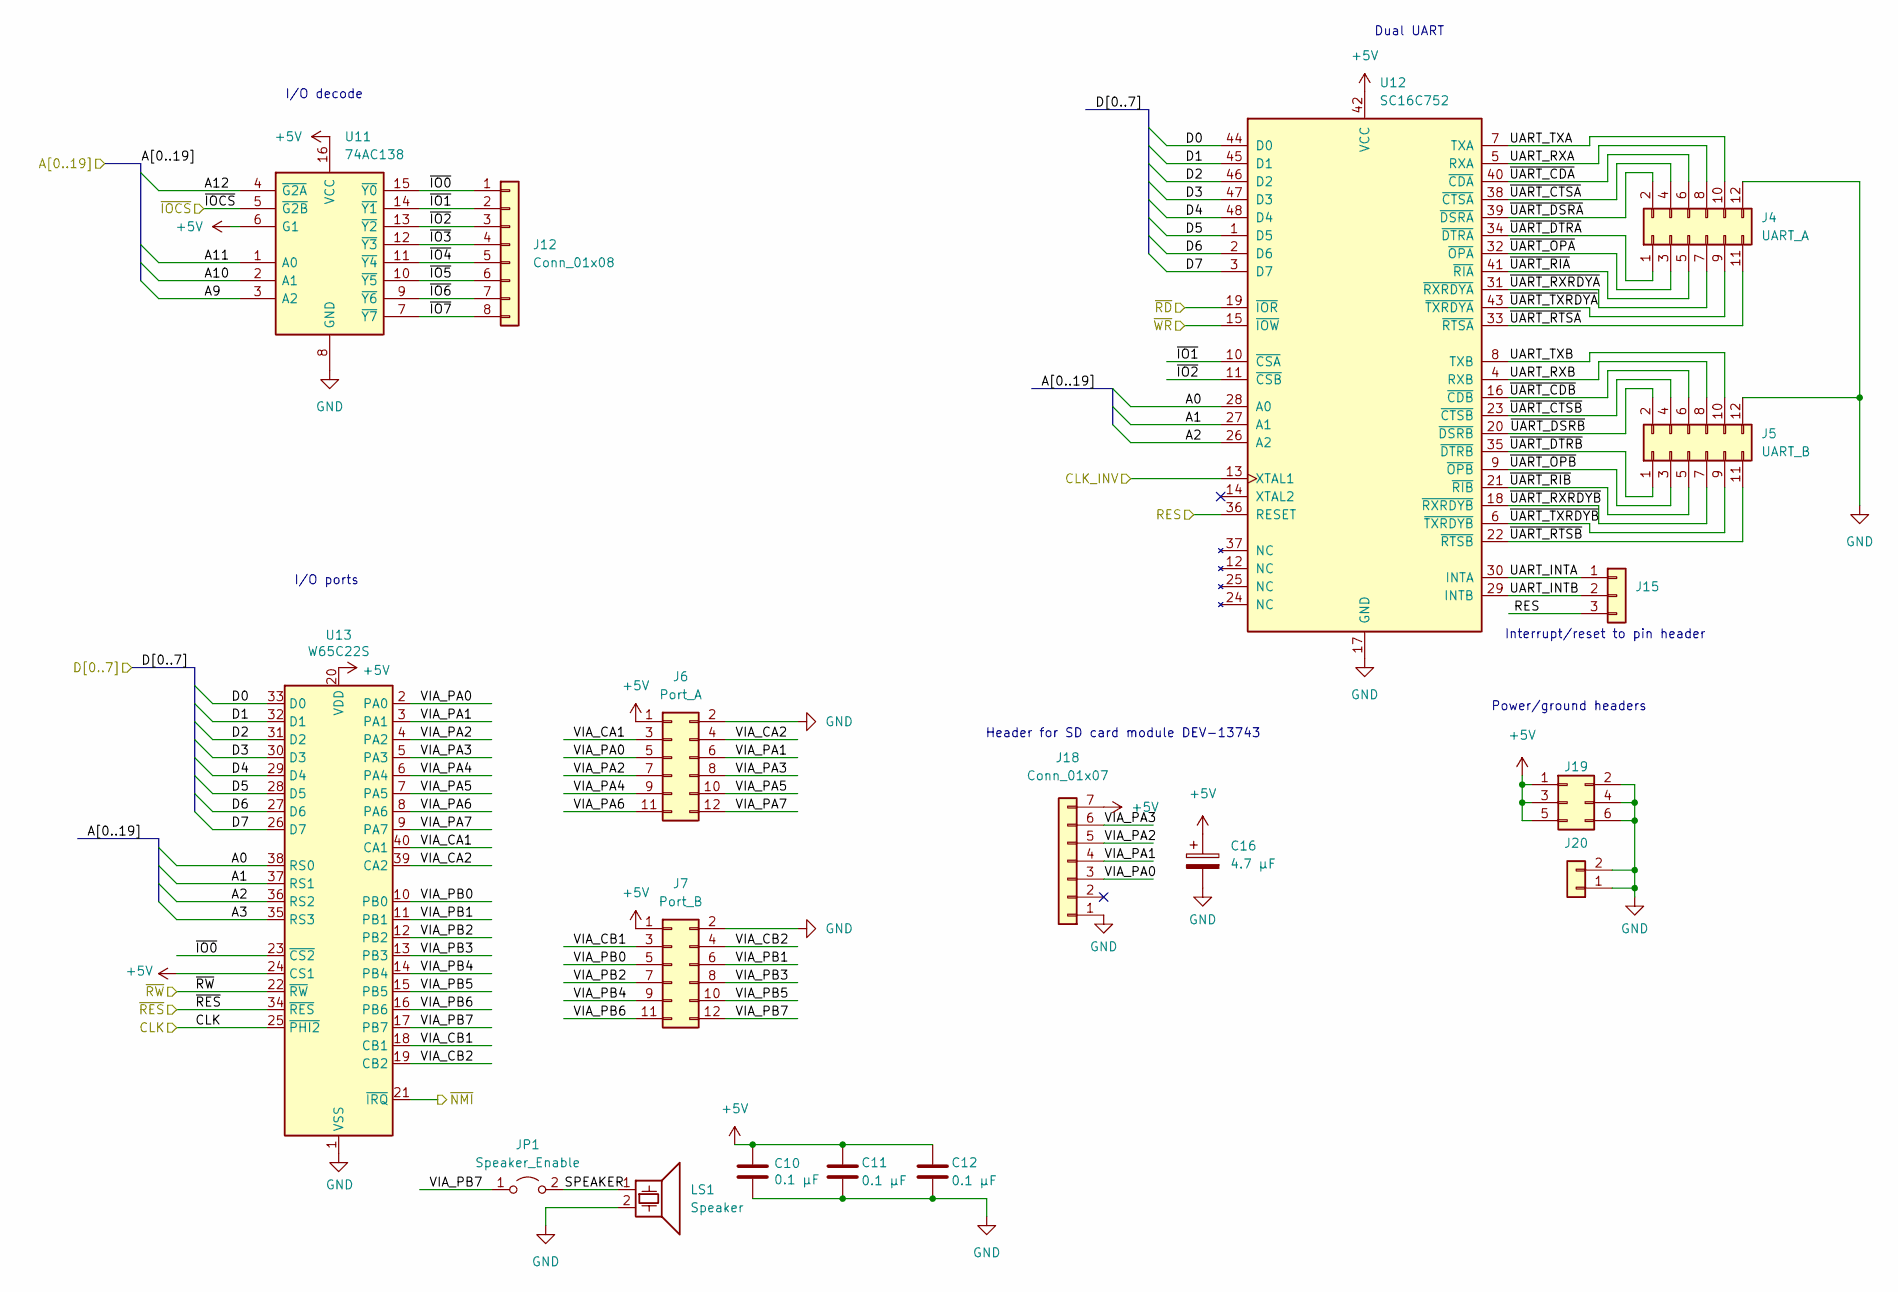
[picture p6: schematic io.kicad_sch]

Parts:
C10, C11, C12: 0.1 µF; C_0603_1608Metric_Pad1.08x0.95mm_HandSolder
C16: 4.7 µF; CP_Radial_D4.0mm_P1.50mm
J4: UART_A
J5: UART_B; PinHeader_2x06_P2.54mm_Vertical
J6: Port_A; PinHeader_2x06_P2.54mm_Vertical
J7: Port_B; PinHeader_2x06_P2.54mm_Vertical
J12: Conn_01x08; PinHeader_1x08_P2.54mm_Vertical
J15: (no value)
J18: Conn_01x07; PinSocket_1x07_P2.54mm_Vertical
J19: Conn_02x06; PinHeader_2x03_P2.54mm_Vertical
J20: Conn_01x02; PinHeader_1x02_P2.54mm_Vertical
JP1: Speaker_Enable; PinHeader_1x02_P2.54mm_Vertical
LS1: Speaker; Buzzer_TDK_PS1240P02BT_D12.2mm_H6.5mm
U11: 74AC138; DIP-16_W7.62mm_Socket
U12: SC16C752; LQFP-48_7x7mm_P0.5mm
U13: W65C22S; DIP-40_W15.24mm_Socket

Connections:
+5V: C10.1, C11.1, C12.1, C16.1, J6.1, J7.1, J18.7, J19.1, J19.3, J19.5, U11.6 (G1), U11.16 (VCC), U12.42 (VCC), U13.20 (VDD), U13.24 (CS1); also elsewhere on the board
/CPU& Bank Address Latching/A0: U12.28 (A0), U13.38 (RS0); also elsewhere on the board
/CPU& Bank Address Latching/A1: U12.27 (A1), U13.37 (RS1); also elsewhere on the board
/CPU& Bank Address Latching/A2: U12.26 (A2), U13.36 (RS2); also elsewhere on the board
/CPU& Bank Address Latching/A3: U13.35 (RS3); also elsewhere on the board
/CPU& Bank Address Latching/A9: U11.3 (A2); also elsewhere on the board
/CPU& Bank Address Latching/A10: U11.2 (A1); also elsewhere on the board
/CPU& Bank Address Latching/A11: U11.1 (A0); also elsewhere on the board
/CPU& Bank Address Latching/A12: U11.4 (~G2A); also elsewhere on the board
/CPU& Bank Address Latching/CLK: U13.25 (~PHI2); also elsewhere on the board
/CPU& Bank Address Latching/CLK_UART: U12.13 (XTAL1); also elsewhere on the board
/CPU& Bank Address Latching/D0: U12.44 (D0), U13.33 (D0); also elsewhere on the board
/CPU& Bank Address Latching/D1: U12.45 (D1), U13.32 (D1); also elsewhere on the board
/CPU& Bank Address Latching/D2: U12.46 (D2), U13.31 (D2); also elsewhere on the board
/CPU& Bank Address Latching/D3: U12.47 (D3), U13.30 (D3); also elsewhere on the board
/CPU& Bank Address Latching/D4: U12.48 (D4), U13.29 (D4); also elsewhere on the board
/CPU& Bank Address Latching/D5: U12.1 (D5), U13.28 (D5); also elsewhere on the board
/CPU& Bank Address Latching/D6: U12.2 (D6), U13.27 (D6); also elsewhere on the board
/CPU& Bank Address Latching/D7: U12.3 (D7), U13.26 (D7); also elsewhere on the board
/CPU& Bank Address Latching/RES: J15.3, U12.36 (RESET); also elsewhere on the board
/CPU& Bank Address Latching/~NMI: U13.21 (~IRQ); also elsewhere on the board
/CPU& Bank Address Latching/~RES: U13.34 (~RES); also elsewhere on the board
/CPU& Bank Address Latching/~RW: U13.22 (~RW); also elsewhere on the board
/IO/SPEAKER: JP1.2 (B), LS1.1
/IO/UART_INTA: J15.1, U12.30 (INTA)
/IO/UART_INTB: J15.2, U12.29 (INTB)
/IO/UART_RXA: J4.8, U12.5 (RXA)
/IO/UART_RXB: J5.8, U12.4 (RXB)
/IO/UART_TXA: J4.10, U12.7 (TXA)
/IO/UART_TXB: J5.10, U12.8 (TXB)
/IO/VIA_CA1: J6.3, U13.40 (CA1)
/IO/VIA_CA2: J6.4, U13.39 (CA2)
/IO/VIA_CB1: J7.3, U13.18 (CB1)
/IO/VIA_CB2: J7.4, U13.19 (CB2)
/IO/VIA_PA0: J6.5, J18.3, U13.2 (PA0)
/IO/VIA_PA1: J6.6, J18.4, U13.3 (PA1)
/IO/VIA_PA2: J6.7, J18.5, U13.4 (PA2)
/IO/VIA_PA3: J6.8, J18.6, U13.5 (PA3)
/IO/VIA_PA4: J6.9, U13.6 (PA4)
/IO/VIA_PA5: J6.10, U13.7 (PA5)
/IO/VIA_PA6: J6.11, U13.8 (PA6)
/IO/VIA_PA7: J6.12, U13.9 (PA7)
/IO/VIA_PB0: J7.5, U13.10 (PB0)
/IO/VIA_PB1: J7.6, U13.11 (PB1)
/IO/VIA_PB2: J7.7, U13.12 (PB2)
/IO/VIA_PB3: J7.8, U13.13 (PB3)
/IO/VIA_PB4: J7.9, U13.14 (PB4)
/IO/VIA_PB5: J7.10, U13.15 (PB5)
/IO/VIA_PB6: J7.11, U13.16 (PB6)
/IO/VIA_PB7: J7.12, JP1.1 (A), U13.17 (PB7)
/IO/~IO0: J12.1, U11.15 (~Y0), U13.23 (~CS2)
/IO/~IO1: J12.2, U11.14 (~Y1), U12.10 (~CSA)
/IO/~IO2: J12.3, U11.13 (~Y2), U12.11 (~CSB)
/IO/~IO3: J12.4, U11.12 (~Y3)
/IO/~IO4: J12.5, U11.11 (~Y4)
/IO/~IO5: J12.6, U11.10 (~Y5)
/IO/~IO6: J12.7, U11.9 (~Y6)
/IO/~IO7: J12.8, U11.7 (~Y7)
/IO/~IOCS: U11.5 (~G2B); also elsewhere on the board
/IO/~UART_CDA: J4.6, U12.40 (~CDA)
/IO/~UART_CDB: J5.6, U12.16 (~CDB)
/IO/~UART_CTSA: J4.4, U12.38 (~CTSA)
/IO/~UART_CTSB: J5.4, U12.23 (~CTSB)
/IO/~UART_DSRA: J4.2, U12.39 (~DSRA)
/IO/~UART_DSRB: J5.2, U12.20 (~DSRB)
/IO/~UART_DTRA: J4.1, U12.34 (~DTRA)
/IO/~UART_DTRB: J5.1, U12.35 (~DTRB)
/IO/~UART_OPA: J4.3, U12.32 (~OPA)
/IO/~UART_OPB: J5.3, U12.9 (~OPB)
/IO/~UART_RIA: J4.5, U12.41 (~RIA)
/IO/~UART_RIB: J5.5, U12.21 (~RIB)
/IO/~UART_RTSA: J4.11, U12.33 (~RTSA)
/IO/~UART_RTSB: J5.11, U12.22 (~RTSB)
/IO/~UART_RXRDYA: J4.7, U12.31 (~RXRDYA)
/IO/~UART_RXRDYB: J5.7, U12.18 (~RXRDYB)
/IO/~UART_TXRDYA: J4.9, U12.43 (~TXRDYA)
/IO/~UART_TXRDYB: J5.9, U12.6 (~TXRDYB)
/Memory/~RD: U12.19 (~IOR); also elsewhere on the board
/Memory/~WR: U12.15 (~IOW); also elsewhere on the board
GND: C10.2, C11.2, C12.2, C16.2, J4.12, J5.12, J6.2, J7.2, J18.1, J19.2, J19.4, J19.6, J20.1, J20.2, LS1.2, U11.8 (GND), U12.17 (GND), U13.1 (VSS); also elsewhere on the board

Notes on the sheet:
Header for SD card module DEV-13743
I/O decode
Dual UART
Power/ground headers
Interrupt/reset to pin header
I/O ports

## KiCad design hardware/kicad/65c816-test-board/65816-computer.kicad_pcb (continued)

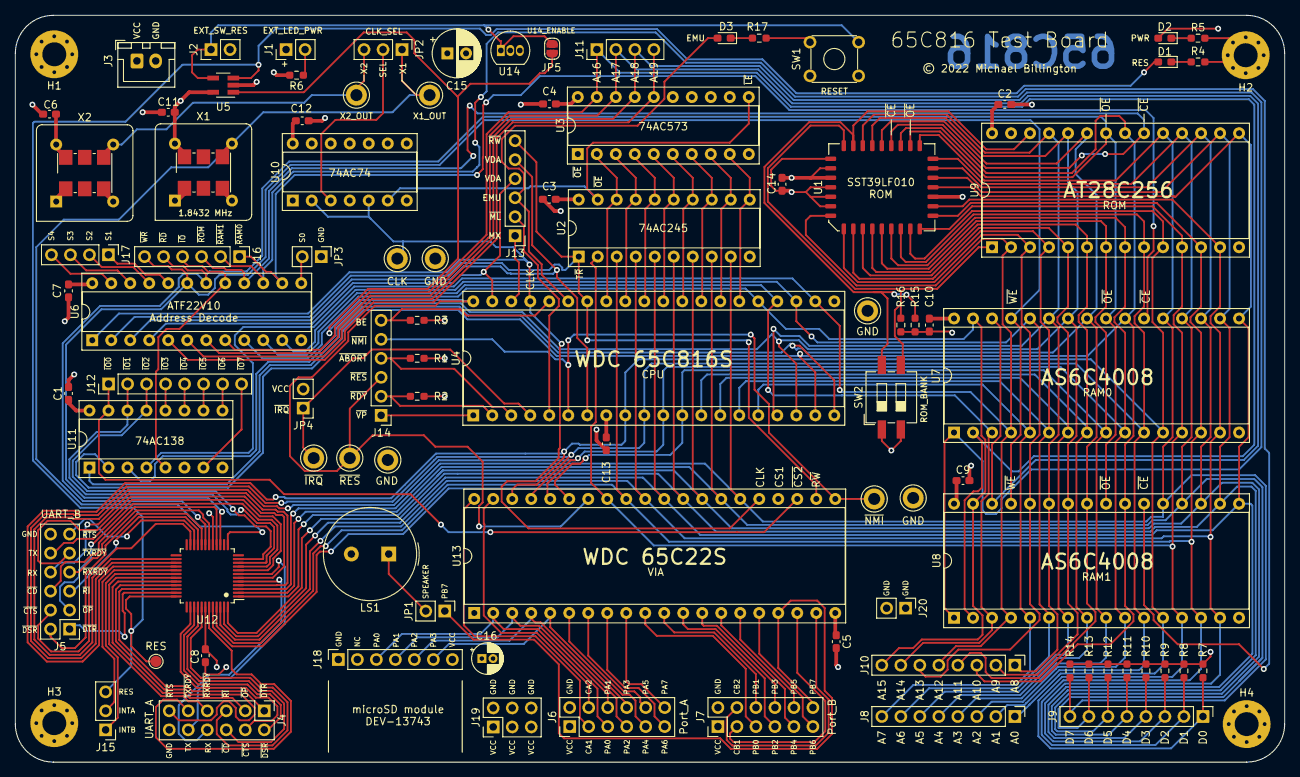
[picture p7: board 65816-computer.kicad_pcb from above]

Board: 4 copper layers, 169.7 x 99.8 mm, 97 parts (0 on the bottom side), 128 nets.

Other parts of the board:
X1_ALT, X2_ALT: Oscillator_SMD_IDT_JU6-6_7.0x5.0mm_P2.54mm

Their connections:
+5V: X1_ALT.1, X1_ALT.6, X2_ALT.1, X2_ALT.6; also elsewhere on the board
/CPU& Bank Address Latching/CLK_UART: X1_ALT.4; also elsewhere on the board
GND: X1_ALT.3, X2_ALT.3; also elsewhere on the board
unnamed 127: X2_ALT.4; also elsewhere on the board

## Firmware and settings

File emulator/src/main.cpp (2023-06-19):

#include "Log.h"
#include "Ram.h"
#include "Rom.h"
#include "Via.h"
#include "Uart.h"
#include "TerminalWrapper.h"
#include "SpeedLimit.h"
#include "DebugSymbols.h"

#include <boost/program_options.hpp>
#include <SystemBus.h>
#include <Cpu65816.h>
#include <Cpu65816Debugger.h>

#define LOG_TAG "MAIN"

std::shared_ptr<TerminalWrapper> getTerminalWrapper(bool mode);

namespace po = boost::program_options;

int executeTestRoutine(Cpu65816& cpu, Cpu65816Debugger &debugger, const Address &address, bool &breakPointHit) {
    breakPointHit = false; // reset
    // Track stack pointer so we know when this returns
    uint16_t startOffset = cpu.getStack()->getStackPointer();
    // Imitate jsr instruction
    cpu.getStack()->push16Bit(0x0000);
    cpu.setProgramAddress(address);
    while (cpu.getStack()->getStackPointer() < startOffset && !breakPointHit) {
        debugger.step();
    }
    if(breakPointHit) {
        return -1; // Test failure
    }
    // Return A register when subroutine returns
    return cpu.getA();
}

int executeTestMode(Cpu65816 &cpu, Cpu65816Debugger &debugger, DebugSymbols symbols) {
    bool breakPointHit = false;
    debugger.doBeforeStep([]() {});
    debugger.doAfterStep([]() {});
    debugger.onBreakPoint([&breakPointHit]() {
        breakPointHit = true;
    });
    debugger.onStp([&cpu, &breakPointHit]() {
        breakPointHit = true;
    });
    const int testWidth = 45;
    // Run test setup first if it is defined
    if(symbols.labels.contains("test_setup")) {
        Address testSetupRoutine = symbols.labels["test_setup"];
        std::cerr << std::left << std::setw(testWidth) << "test_setup";
        uint16_t setupResult = executeTestRoutine(cpu, debugger, testSetupRoutine, breakPointHit);
        if(setupResult != 0) {
            std::cerr << " [ FAIL ]" << std::endl;
            return 1;
        }
        std::cerr << " [  OK  ]" << std::endl << std::endl;
    }
    // Iterate labels, run any that look like test routines
    int testsExecuted = 0;
    int testsPassed = 0;
    int testsFailed = 0;
    for (auto & itr : symbols.labels) {
        auto label = itr.first;
        if(label == "test_setup" || !label.starts_with("test_")) {
            // Not a test
            continue;
        }
        std::cerr << std::left << std::setw(testWidth) << label;
        // Run the test
        int testResult = executeTestRoutine(cpu, debugger, itr.second, breakPointHit);
        // Record result
        testsExecuted++;
        if(testResult == 0) {
            testsPassed++;
            std::cerr << " [ PASS ]" << std::endl;
        } else if (testResult == -1) {
            testsFailed++;
            std::cerr << " [ ERROR ]" << std::endl;
        } else {
            testsFailed++;
            std::cerr << " [ FAIL ]" << std::endl;
        }
    }
    std::cerr << std::endl << testsExecuted << " tests executed. " << testsPassed << " passed, " << testsFailed
              << " failed/errored." << std::endl;
    return testsFailed;
}

int executeFromReset(Cpu65816& cpu, Cpu65816Debugger& debugger) {
    // Run full system from reset.
    Log::vrb(LOG_TAG).str("+++ Program starting +++").show();
    debugger.setBreakPoint(Address(0x00, 0x0005));
    debugger.doBeforeStep([]() {});
    debugger.doAfterStep([]() {});

    bool breakPointHit = false;
    debugger.onBreakPoint([&breakPointHit]() {
        breakPointHit = true;
    });
    debugger.onStp([&cpu, &breakPointHit]() {
        // Trigger clean exit when STP is used.
        breakPointHit = true;
    });
    SpeedLimit speedLimit(4000000);
    while (!breakPointHit) {
        debugger.step();
        speedLimit.apply(cpu.getTotalCyclesCounter());
    }
    debugger.dumpCpu();
    Log::vrb(LOG_TAG).str("+++ Program completed +++").show();
    return cpu.getA();
}

int main(int argc, char **argv) {
    std::string romPath;
    std::string kernelPath;
    std::string testPath;
    bool traceLog = false;
    bool testMode;
    // Parse command-line options
    try {
        po::options_description desc{"Options"};
        desc.add_options()
                ("help,h", "Show help")
                ("rom", po::value(&romPath),
                 "Set ROM image, 8192 byte file to be loaded at $00e000. This option is required unless a test image is specified.")
                ("kernel", po::value(&kernelPath),
                 "Set kernel image, 8192 byte file to be loaded at $010000. If this option is used, ROM must be set. SD card emulation is not implemented, so this is intended to be used with a ROM image which has been modified to boot directly into the kernel code instead of attempting to load it from disk.")
                ("test", po::value(&testPath),
                 "Set test image, 8192 byte file to be loaded into RAM at $00e000. This is a different execution mode, intended for running unit tests. No ROM or Kernel image is required, and the machine will not emulate a proper console. Instead, the emulator will load a labels file, execute the test setup subroutine ('test_setup'), then execute each test subroutine (labels beginning with 'test_'). If a test is successful, it should return with the value0 in the accumulator, any other value indicates test failure.")
                ("trace", po::bool_switch(&traceLog), "Enable detailed trace-level logging.");
        po::variables_map vm;
        store(parse_command_line(argc, argv, desc), vm);
        po::notify(vm);
        if (vm.count("help")) {
            // Show help
            std::cerr << desc << "\n";
            return 0;
        }
        if(traceLog) {
            Log::trc(LOG_TAG).enable();
        }
        // Error if we get incompatible options
        if(romPath.empty() && testPath.empty()) {
            std::cerr << "Either a ROM or test image must be specified." << '\n';
            return 1;
        }
        testMode = !testPath.empty();
    } catch (const boost::program_options::error &ex) {
        // Bad option
        std::cerr << ex.what() << '\n';
        return 1;
    }

    // Create the system
    Ram ram = Ram(16);
    Via via = Via();
    TerminalWrapper terminalWrapper = TerminalWrapper(testMode);
    Uart uart = Uart(&terminalWrapper);

    SystemBus systemBus = SystemBus();
    systemBus.registerDevice(&via);
    systemBus.registerDevice(&uart);

    // Always initialise this, though we don't always use it
    DebugSymbols symbols = DebugSymbols();
    Rom rom = Rom(testMode ? testPath : romPath);
    if(testMode) {
        // Load code into RAM in test mode, so we can test eg. self-modifying code
        ram.loadFromFile(testPath, Address(0x00, 0xe000), 8192);
        symbols.loadSymbolsForBinary(testPath);
    } else {
        systemBus.registerDevice(&rom);
        symbols.loadSymbolsForBinary(romPath);
    }
    if (!kernelPath.empty()) {
        ram.loadFromFile(kernelPath, Address(0x01, 0x0000), 8192);
        symbols.loadSymbolsForBinary(kernelPath);
    }
    systemBus.registerDevice(&ram);

    auto nmi = via.getIrq();
    auto irq = std::make_shared<InterruptStatus>();

    Cpu65816 cpu(systemBus, nmi, irq);
    Cpu65816Debugger debugger(cpu, symbols, traceLog);

    if(testMode) {
        return executeTestMode(cpu, debugger, symbols);
    } else {
        return executeFromReset(cpu, debugger);
    }

}

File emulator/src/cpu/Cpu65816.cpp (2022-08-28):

/*
 * This file is part of the 65816 Emulator Library.
 * Copyright (c) 2018 Francesco Rigoni.
 *
 * https://github.com/FrancescoRigoni/Lib65816
 *
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
 * You should have received a copy of the GNU General Public License
 * along with this program. If not, see <http://www.gnu.org/licenses/>.
 */

#include "Cpu65816.h"

#include <utility>

#ifdef EMU_65C02
#define LOG_TAG "Cpu65C02"
#else
#define LOG_TAG (mCpuStatus.emulationFlag() ? "Cpu6502" : "Cpu65816")
#endif

Cpu65816::Cpu65816(SystemBus &systemBus, std::shared_ptr<InterruptStatus> nmi, std::shared_ptr<InterruptStatus> irq) :
        mSystemBus(systemBus),
        mStack(&mSystemBus),
        nmi(nmi),
        irq(irq) {
    mPins.NMI = nmi->get();
}


void Cpu65816::setXL(uint8_t x) {
    mX = x;
}

void Cpu65816::setYL(uint8_t y) {
    mY = y;
}

void Cpu65816::setX(uint16_t x) {
    mX = x;
}

void Cpu65816::setY(uint16_t y) {
    mY = y;
}

void Cpu65816::setA(uint16_t a) {
    mA = a;
}

uint16_t Cpu65816::getA() {
    return mA;
}

Address Cpu65816::getProgramAddress() {
    return mProgramAddress;
}

Stack *Cpu65816::getStack() {
    return &mStack;
}

CpuStatus *Cpu65816::getCpuStatus() {
    return &mCpuStatus;
}


/**
 * Resets the cpu to its initial state.
 * */
void Cpu65816::reset() {
    setRESPin(true);
    mCpuStatus.setEmulationFlag();
    mCpuStatus.setAccumulatorWidthFlag();
    mCpuStatus.setIndexWidthFlag();
    mX &= 0xFF;
    mY &= 0xFF;
    mD = 0x0;
    mStack = Stack(&mSystemBus);
    mProgramAddress = Address(0x00, mSystemBus.readTwoBytes(Address(0x00, INTERRUPT_VECTOR_EMULATION_RESET)));
}

void Cpu65816::setRESPin(bool value) {
    if (value == false && mPins.RES == true) {
        reset();
    }
    mPins.RES = value;
}

void Cpu65816::setRDYPin(bool value) {
    mPins.RDY = value;
}

bool Cpu65816::executeNextInstruction() {
    if (mPins.RES) {
        return false;
    }
    if ((irq->get()) && (!mCpuStatus.interruptDisableFlag())) {
        /*
        The program bank register (PB, the A16-A23 part of the address bus) is pushed onto the hardware stack (65C816/65C802 only when operating in native mode).
        The most significant byte (MSB) of the program counter (PC) is pushed onto the stack.
        The least significant byte (LSB) of the program counter is pushed onto the stack.
        The status register (SR) is pushed onto the stack.
        The interrupt disable flag is set in the status register.
        PB is loaded with $00 (65C816/65C802 only when operating in native mode).
        PC is loaded from the relevant vector (see tables).
        */
        if (!mCpuStatus.emulationFlag()) {
            mStack.push8Bit(mProgramAddress.getBank());
            mStack.push16Bit(mProgramAddress.getOffset());
            mStack.push8Bit(mCpuStatus.getRegisterValue());
            mCpuStatus.setInterruptDisableFlag();
            mProgramAddress = Address(0x00, mSystemBus.readTwoBytes(Address(0x00, INTERRUPT_VECTOR_NATIVE_IRQ)));
        } else {
            mStack.push16Bit(mProgramAddress.getOffset());
            mStack.push8Bit(mCpuStatus.getRegisterValue());
            mCpuStatus.setInterruptDisableFlag();
            mProgramAddress = Address(0x00, mSystemBus.readTwoBytes(Address(0x00, INTERRUPT_VECTOR_EMULATION_BRK_IRQ)));
        }
    }
    // Edge detect NMI
    bool newNmi = nmi->get();
    if(!newNmi && mPins.NMI) {
        // De-activated
        mPins.NMI = false;
    } else if(newNmi && !mPins.NMI) {
        // Activated
        mPins.NMI = true;
        if (!mCpuStatus.emulationFlag()) {
            mStack.push8Bit(mProgramAddress.getBank());
            mStack.push16Bit(mProgramAddress.getOffset());
            mStack.push8Bit(mCpuStatus.getRegisterValue());
            mCpuStatus.setInterruptDisableFlag();
            mProgramAddress = Address(0x00, mSystemBus.readTwoBytes(Address(0x00, INTERRUPT_VECTOR_NATIVE_NMI)));
        } else {
            mStack.push16Bit(mProgramAddress.getOffset());
            mStack.push8Bit(mCpuStatus.getRegisterValue());
            mCpuStatus.setInterruptDisableFlag();
            mProgramAddress = Address(0x00, mSystemBus.readTwoBytes(Address(0x00, INTERRUPT_VECTOR_EMULATION_NMI)));
        }
    }
    // Fetch the instruction
    const uint8_t instruction = mSystemBus.readByte(mProgramAddress);
    OpCode opCode = OP_CODE_TABLE[instruction];
    // Execute it
    return opCode.execute(*this);
}

bool Cpu65816::accumulatorIs8BitWide() {
    // Accumulator is always 8 bit in emulation mode.
    if (mCpuStatus.emulationFlag()) return true;
        // Accumulator width set to one means 8 bit accumulator.
    else return mCpuStatus.accumulatorWidthFlag();
}

bool Cpu65816::accumulatorIs16BitWide() {
    return !accumulatorIs8BitWide();
}

bool Cpu65816::indexIs8BitWide() {
    // Index is always 8 bit in emulation mode.
    if (mCpuStatus.emulationFlag()) return true;
        // Index width set to one means 8 bit accumulator.
    else return mCpuStatus.indexWidthFlag();
}

bool Cpu65816::indexIs16BitWide() {
    return !indexIs8BitWide();
}

void Cpu65816::addToCycles(int cycles) {
    mTotalCyclesCounter += cycles;
    mSystemBus.clockTick(cycles);
}

void Cpu65816::subtractFromCycles(int cycles) {
    mTotalCyclesCounter -= cycles;
}

void Cpu65816::addToProgramAddress(int bytes) {
    mProgramAddress.incrementOffsetBy(bytes);
}

void Cpu65816::addToProgramAddressAndCycles(int bytes, int cycles) {
    addToCycles(cycles);
    addToProgramAddress(bytes);
}

uint16_t Cpu65816::indexWithXRegister() {
    return indexIs8BitWide() ? Binary::lower8BitsOf(mX) : mX;
}

uint16_t Cpu65816::indexWithYRegister() {
    return indexIs8BitWide() ? Binary::lower8BitsOf(mY) : mY;
}

void Cpu65816::setProgramAddress(const Address &address) {
    mProgramAddress = address;
}

uint64_t Cpu65816::getTotalCyclesCounter() const {
    return mTotalCyclesCounter;
}

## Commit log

2022-01-10 add ROM
    [system.cfg]
2022-01-10 add KiCad project files for current design
    [65816-computer.sch, cpu.sch, memory.sch]
2022-01-22 upgrade project files to Kicad 6.0
    [65816-computer.kicad_sch, 65816-computer.sch, cpu.kicad_sch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]
2022-01-31 update computer, move test program to use native mode
    [65816-computer.kicad_sch, cpu.kicad_sch, memory.kicad_sch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]
2022-02-05 update example program to use native mode interrupts
    [system.cfg]
2022-02-05 connect IRQ output of 65C22 to CPU NMI
    [65816-computer.kicad_sch, cpu.kicad_sch, memory.kicad_sch]
2022-02-27 add extra 512 kB RAM, 74AC138 for future use
    [65816-computer.kicad_sch, cpu.kicad_sch, memory.kicad_sch]
2022-03-02 update address decoding, extend README
    [65816-computer.kicad_sch, memory.kicad_sch]
2022-03-05 separate I/O schematic page, add SC16C752 for future use
    [65816-computer.kicad_sch, cpu.kicad_sch, io.kicad_sch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]
2022-03-10 bump to C++17, fix ROM loading, load reset vector from ROM on start - should really be requested from system bus when needed.
    [main.cpp]
2022-03-14 add basic 65C22 VIA emulation for free-running timer; interrupt is not connected.
2022-03-14 connect UART to circuit
    [65816-computer.kicad_sch, cpu.kicad_sch, io.kicad_sch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]
2022-03-26 update emulation to improve interrupt handling
2022-03-26 switch off logging
2022-03-30 implement character I/O with curses instead (buffering issues)
    [Uart.cpp, main.cpp]
2022-04-01 update ROM to UART test (does not work on real hardware)
2022-04-01 move all hardware files to hardware folder
    [65816-computer.kicad_sch, cpu.kicad_sch, io.kicad_sch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]
2022-04-11 remove curses, use plain non-canonical terminal input instead (avoids clearning the screen)
    [Uart.cpp]
2022-04-11 update hardware files to match current WIP design
    [65816-computer.kicad_pcb, 65816-computer.kicad_sch, cpu.kicad_sch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]
2022-04-12 add software/ dir for test kernel
    [system.cfg]
2022-04-12 split out interrupts
2022-04-18 fix/annotate suspected lib65816 bugs in 16-bit ADC and SBC
    [OpCode_ADC.cpp]
2022-04-19 add some test C functions, compiled to assembly and translated to ca65 syntax
2022-05-01 update schematic, add draft PCB
    [65816-computer.kicad_pcb, 65816-computer.kicad_sch, cpu.kicad_sch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]
2022-05-07 pcb updates
    [65816-computer.kicad_pcb, 65816-computer.kicad_sch, cpu.kicad_sch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]
2022-05-07 add gerbers for test board
    [65816-computer-B_Cu.gbr, 65816-computer-B_Mask.gbr, 65816-computer-B_Silkscreen.gbr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]
2022-06-17 update ROM - WIP SD card testing.
    [system.cfg]
2022-06-24 start testing access of ROM functions via software interrupt
2022-07-05 add bootloader placeholder
    [boot.cfg]
2022-07-05 move SD block read to software interrupt (COP) routine
2022-07-05 implement software interrupt (COP) routines for printing char, reading char, convert some ROM code to use this
2022-07-05 progress towards reading multiple blocks from software interrupt (COP) routine - most code commented
2022-07-12 work on SD boot, 3 attempts to reset card, allow loading multiple blocks of data through software interrupt
2022-07-17 update test programs - bootloader loading 8k kernel now but not to the address we would like to use.
    [kernel_tmp.cfg]
2022-07-25 switch to far addressing in some places - a lot of this code does not work when DBR is not bank 0.
2022-08-08 fixed memory map in hardware, UART is now at correct memory location
2022-08-13 update XCE instruction in emulator
    found that switching from native mode to emulation moe does not switch index and accumulator width to 16-bit on real CPU
2022-08-13 update emulated VIA to return its startup default for interrupt enable register (IER)
2022-08-13 indicate that emulated UART always ready / has empty TX register
2022-08-13 update emulator software interrupt handling
    COP instruction was setting program counter to $ffe4, should read address at $ffe4 and set program counter to that value instead.
2022-08-25 TerminalWrapper to use unix socket instead of stdio
2022-08-28 update emulator to remove bugs with characters 0x00 and > 0x7f, also attempt to slow it down to match speed of hardware
    [Cpu65816.cpp, Uart.cpp]
2022-10-15 reorganise hardware folder to allow multiple PCB's
    [65816-computer-B_Cu.gbr, 65816-computer-B_Mask.gbr, 65816-computer-B_Silkscreen.gbr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]
2022-10-15 add i2c breakout board
    [i2c-test-board.kicad_pcb, i2c-test-board.kicad_sch]
2023-01-08 update bootloader code (not using ramdisk)
    [kernel_tmp.cfg]
2023-01-08 placeholder for snake game
    [snake.cfg]
2023-03-29 start manually compiling snake game
    [snake.cfg]
2023-03-29 progress on porting snake. mainly notes at this stage
    [snake.cfg]
2023-05-03 add example unit test project, locate .lbl file for binary output (not parsing yet)
    [system.cfg]
2023-05-05 add --trace option to emulator, to print every CPU instruction being executed
2023-05-05 replace trace output, now includes label names when program counter hits them
    [kernel_tmp.cfg]
2023-05-05 switch test program to print "Hello, world!" instead of "z".
2023-05-06 add test program which hexdumps full 8KiB of program loaded from SD - definitely not loading correctly
    [hexdump.cfg]
2023-06-13 add automated build
    this adds an initial Dockerfile defining build dependencies, a build.sh to define steps, and GitHub action to run the script each change.
    some of the trickier stuff (eg. PLD file generation) is not included at this stage.
2023-06-17 fix emulator bugs with xce resetting stack unnecessarily, and test hanging when 'brk' is triggered (will now fail test)
    in-progress random number functions are now in standalone file so they can be tested
    [test.cfg]
2023-06-19 isolate tests a bit better, add new ERROR label for when the breakpoint at $0000 fires
    [main.cpp]

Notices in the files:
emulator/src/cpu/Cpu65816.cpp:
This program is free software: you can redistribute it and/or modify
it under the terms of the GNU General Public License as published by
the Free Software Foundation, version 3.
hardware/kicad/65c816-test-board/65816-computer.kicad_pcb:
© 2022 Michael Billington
